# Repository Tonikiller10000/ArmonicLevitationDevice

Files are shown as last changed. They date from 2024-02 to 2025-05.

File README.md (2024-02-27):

# ArmonicLevitationDevice

## Description:
<table>
  <tr>
    <td> 
      This levitation device uses an NE555 with an TC78H621FNG Dual-Bridge driver to generate a 40KHz sine wave signal witch is sent back at the rigth distance to make zones of high and low pressure in witch it can trap small objects.
    </td>
    <td>
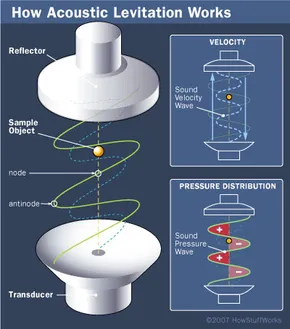
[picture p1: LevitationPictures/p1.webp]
       </td>
  </tr>
</table>

<table>
  <tr>
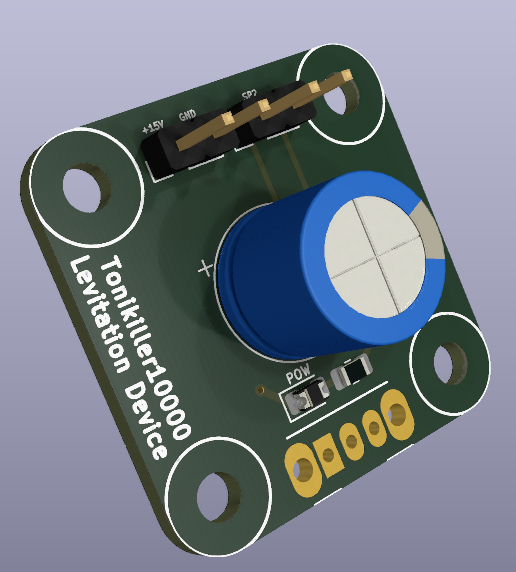
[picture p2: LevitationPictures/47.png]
    <td></td>
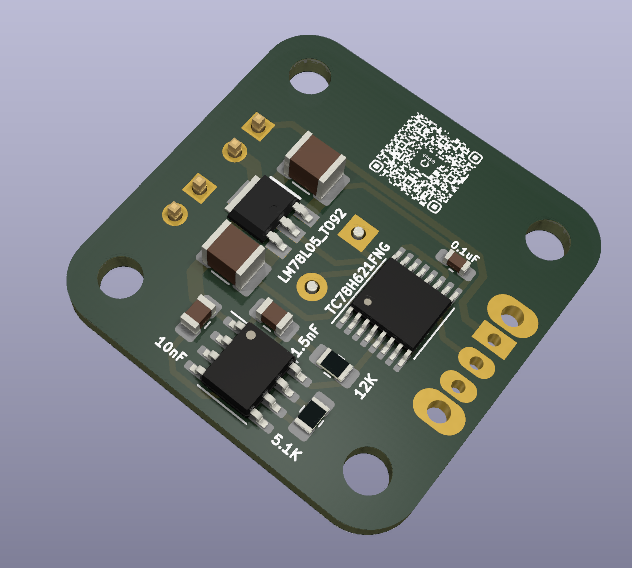
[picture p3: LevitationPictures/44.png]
    <td></td>
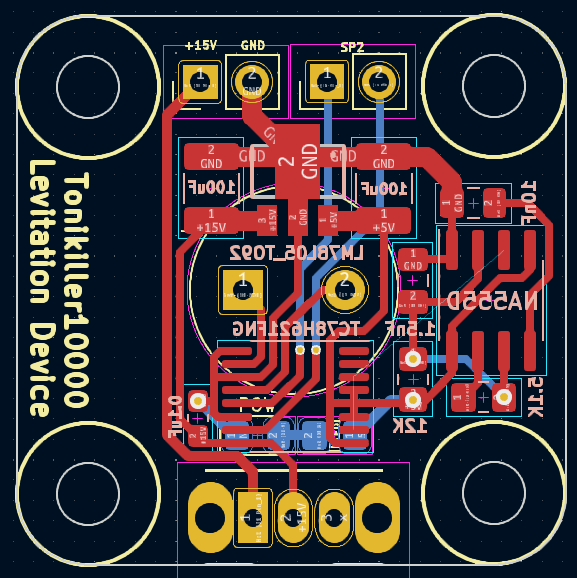
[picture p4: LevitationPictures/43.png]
    <td></td>
  </tr>
</table>

## Schematic:
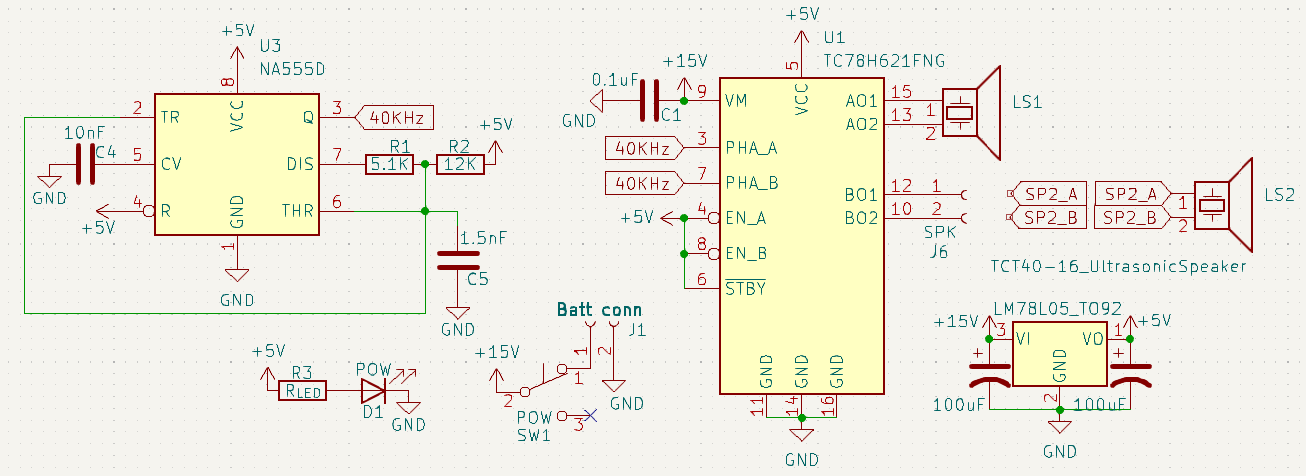
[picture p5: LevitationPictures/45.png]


## How/where to use:
It can be powered with a 9V battery. (5-15v operating voltage range) 
Because of it`s design, multiple tipes of transmiters/transducers can be used by bending the pins. 
To use it, you can use only one board/transmitter ans a close flat surface to reflect the wave. 
For a stronger hold, you can use another transmitter connected to the SP2 pins.

> [!IMPORTANT]
> Change the distance between the transmitter1 and the surface/transmitter2 to create the nodes and antinodes for the project to work.

<table>
  <tr>
    <td> 
    This king of technology, can be used in medical industry to observe and experiment with liquids without making contact with them.</td>
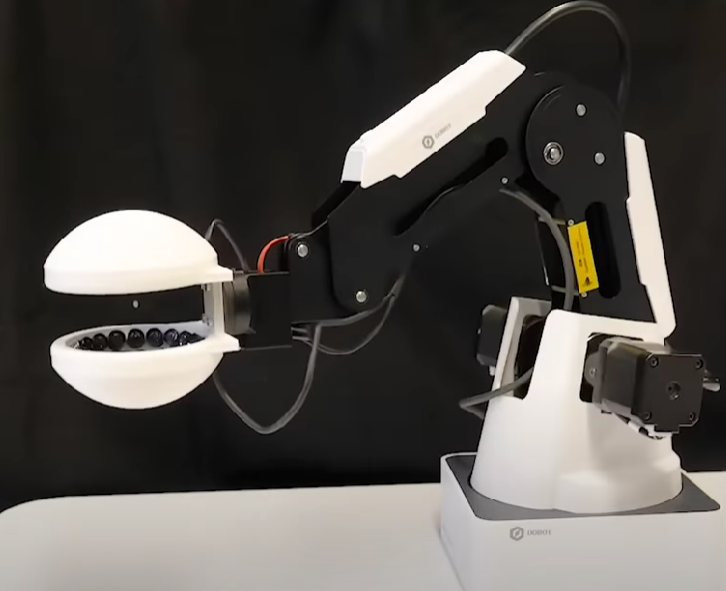
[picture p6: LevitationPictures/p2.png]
    <td></td>
  </tr>
</table>

## Links:
- TC78H621FNG datasheet (Dual-Bridge driver): https://toshiba.semicon-storage.com/info/TC78H621FNG_datasheet_en_20170410.pdf?did=57992&prodName=TC78H621FNG
- 78L05 datasheet (voltage regulator): https://www.sparkfun.com/datasheets/Components/LM7805.pdf
- NE555 datasheet (timer): https://pdf1.alldatasheet.com/datasheet-pdf/view/17972/PHILIPS/NE555.html
- Ultrasonic transducer: https://www.murata.com/-/media/webrenewal/products/sensor/ultrasonic/open/datasheet_maopn.ashx
- general transducers: https://tecsho.com/Download/Download/126816/fp

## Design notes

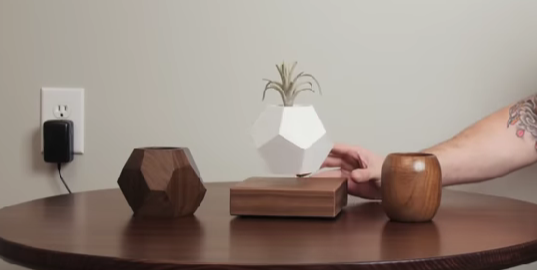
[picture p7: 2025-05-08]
LevitationPictures/Screenshot 2024-01-10 024258.png

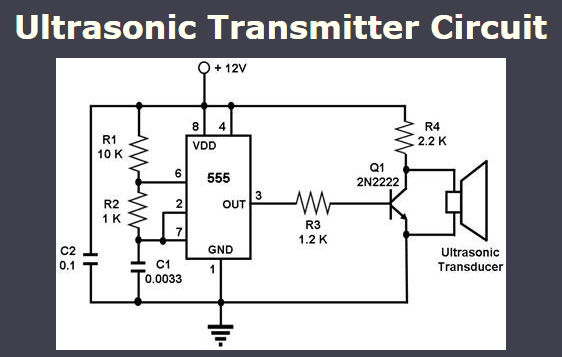
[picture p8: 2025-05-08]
LevitationPictures/{7252BA24-0894-4667-9A59-82356E71AA2C}.png

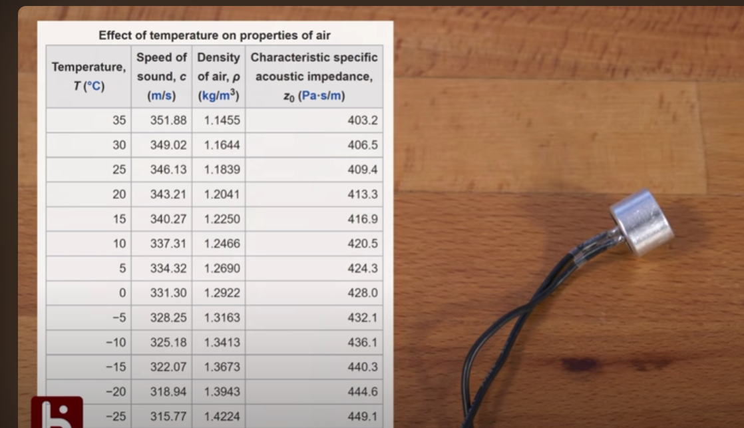
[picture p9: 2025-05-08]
LevitationPictures/Screenshot 2023-12-14 022056.png

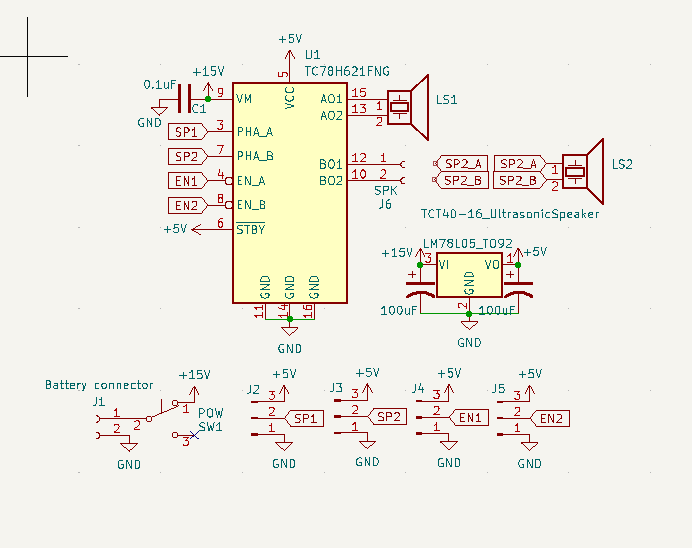
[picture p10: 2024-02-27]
LevitationPictures/sch.png

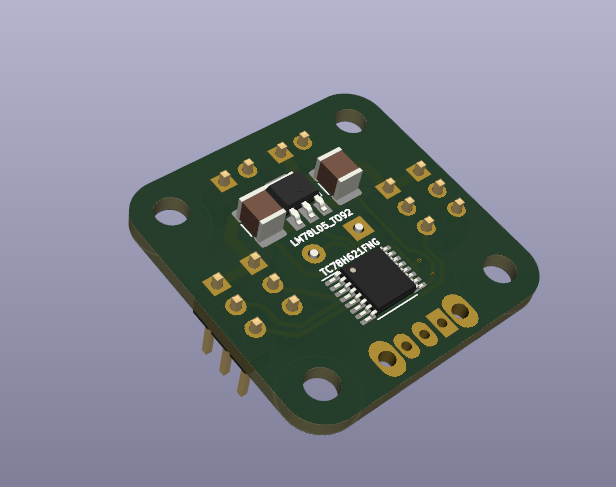
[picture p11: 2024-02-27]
LevitationPictures/down.png

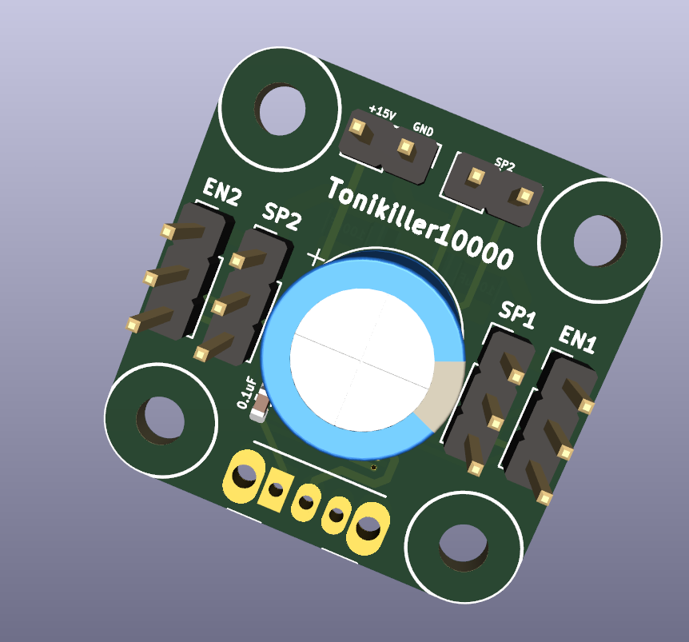
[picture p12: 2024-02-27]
LevitationPictures/up.png

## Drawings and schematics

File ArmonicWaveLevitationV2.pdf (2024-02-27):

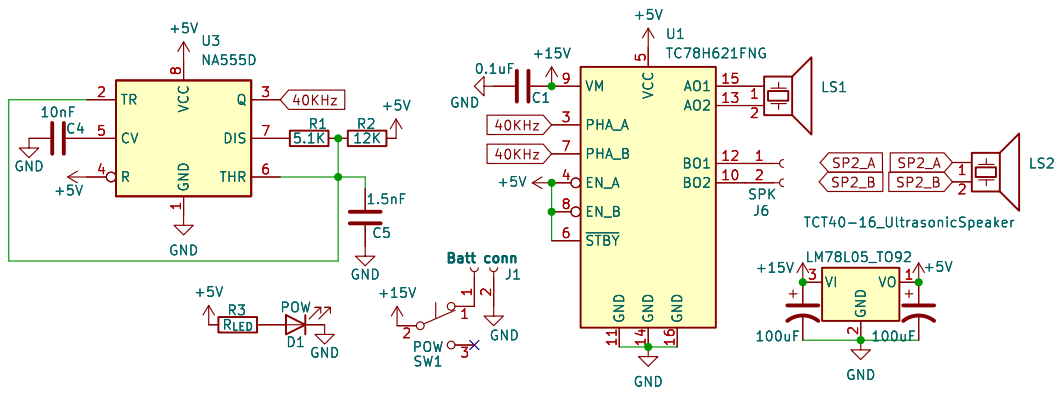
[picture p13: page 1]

Id: 1/1 Title: File: ArmonicWaveLevitation.kicad_sch Sheet: / GND

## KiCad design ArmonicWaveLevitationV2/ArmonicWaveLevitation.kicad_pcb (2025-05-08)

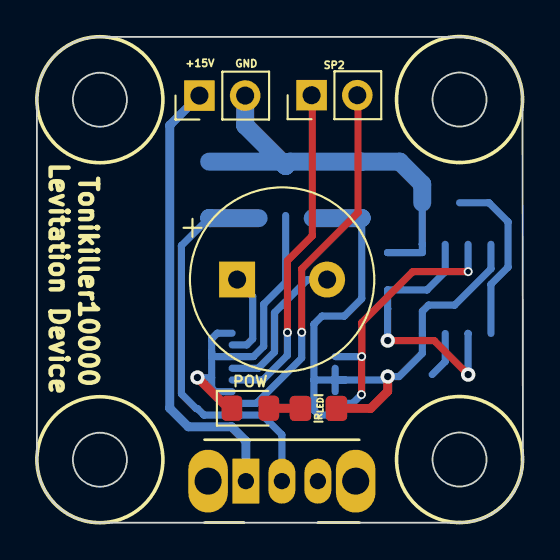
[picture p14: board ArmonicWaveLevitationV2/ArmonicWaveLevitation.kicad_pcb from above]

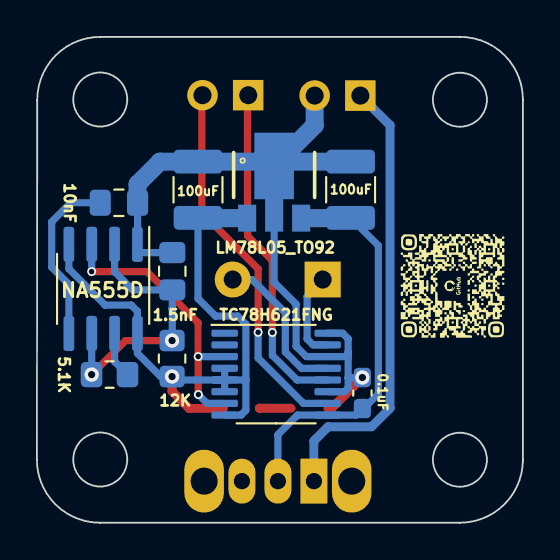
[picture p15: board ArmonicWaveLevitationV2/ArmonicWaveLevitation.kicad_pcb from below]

Board: 2 copper layers, 27.0 x 27.0 mm, 16 parts (10 on the bottom side), 13 nets.

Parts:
C1: 0.1uF; C_0603_1608Metric_Pad1.08x0.95mm_HandSolder
C2, C3: 100uF; C_1210_3225Metric_Pad1.33x2.70mm_HandSolder
C4: 10nF; C_0805_2012Metric_Pad1.18x1.45mm_HandSolder
C5: 1.5nF; C_0805_2012Metric_Pad1.18x1.45mm_HandSolder
D1: POW; D_0805_2012Metric_Pad1.15x1.40mm_HandSolder
J1: Batt conn; PinHeader_1x02_P2.54mm_Vertical
J6: SPK; PinHeader_1x02_P2.54mm_Vertical
LS1: TCT40-16_UltrasonicSpeaker; CP_Radial_D10.0mm_P5.00mm
R1: 5.1K; R_0805_2012Metric_Pad1.20x1.40mm_HandSolder
R2: 12K; R_0805_2012Metric_Pad1.20x1.40mm_HandSolder
R3: R_{LED}; R_0805_2012Metric_Pad1.20x1.40mm_HandSolder
SW1: POW; SW_CuK_OS102011MA1QN1_SPDT_Angled
U1: TC78H621FNG; TSSOP-16_4.4x5mm_P0.65mm
U2: LM78L05_TO92; PK(R-PSSO-F3)
U3: NA555D; SOIC-8_3.9x4.9mm_P1.27mm

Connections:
40KHz: U1.3 (PHA_A), U1.7 (PHA_B), U3.3 (Q)
+5V: C3.1, R2.2, R3.1, U1.4 (EN_A), U1.5 (VCC), U1.6 (~STBY), U1.8 (EN_B), U2.1 (VO), U3.4 (R), U3.8 (VCC)
+15V: C1.2, C2.1, SW1.2 (B), U1.9 (VM), U2.3 (VI)
GND: C1.1, C2.2, C3.2, C4.1, C5.1, D1.1 (K), J1.2, U1.11 (GND), U1.14 (GND), U1.16 (GND), U2.2 (GND), U3.1 (GND)
unnamed: D1.2 (A), R3.2
unnamed: J1.1, SW1.1 (A)
unnamed: J6.1, U1.12 (BO1)
unnamed: J6.2, U1.10 (BO2)
unnamed: LS1.1, U1.15 (AO1)
unnamed: LS1.2, U1.13 (AO2)
unnamed: C4.2, U3.5 (CV)
unnamed: R1.1, U3.7 (DIS)
unnamed: C5.2, R1.2, R2.1, U3.2 (TR), U3.6 (THR)

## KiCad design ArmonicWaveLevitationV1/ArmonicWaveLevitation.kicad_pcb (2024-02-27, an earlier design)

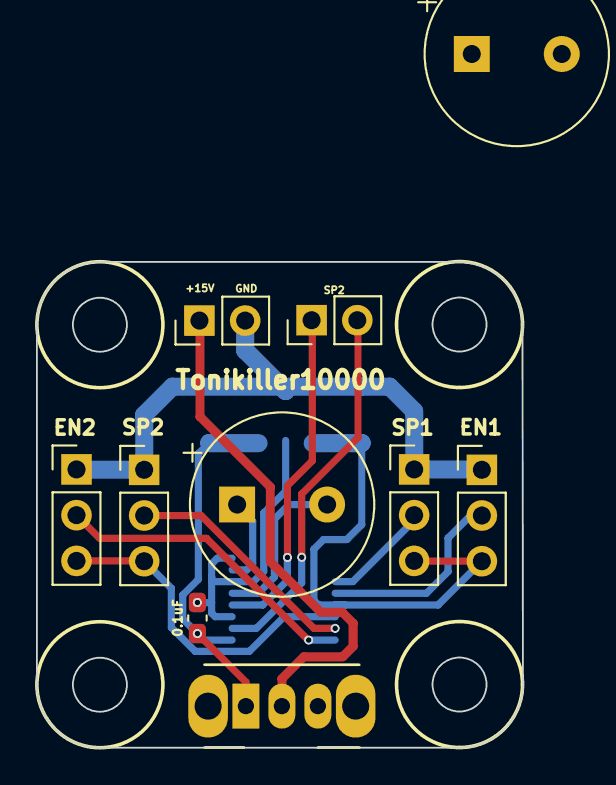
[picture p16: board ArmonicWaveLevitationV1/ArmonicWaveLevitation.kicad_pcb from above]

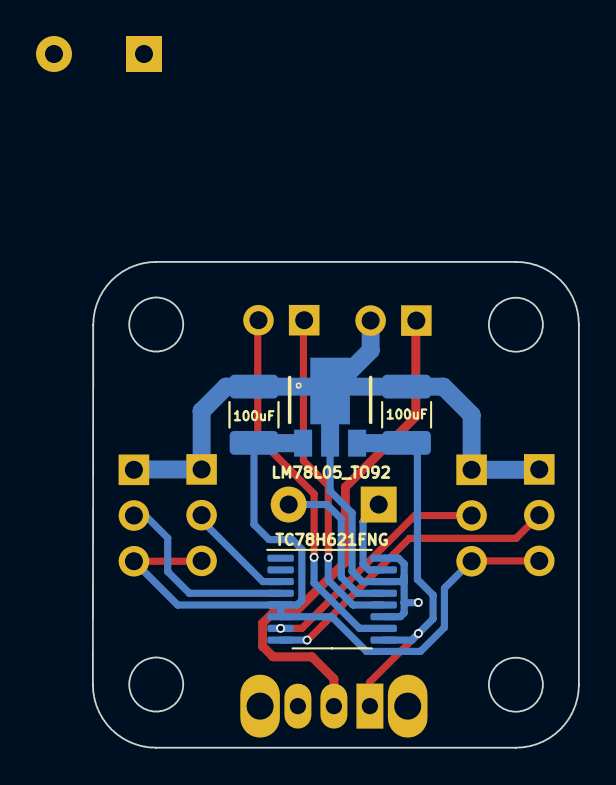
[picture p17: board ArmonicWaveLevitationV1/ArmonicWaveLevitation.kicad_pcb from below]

Board: 2 copper layers, 27.0 x 27.0 mm, 14 parts (4 on the bottom side), 12 nets.

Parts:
C1: 0.1uF; C_0603_1608Metric_Pad1.08x0.95mm_HandSolder
C2, C3: 100uF; C_1210_3225Metric_Pad1.33x2.70mm_HandSolder
J1: Battery connector; PinHeader_1x02_P2.54mm_Vertical
J2: SP1; PinHeader_1x03_P2.54mm_Vertical
J3: SP2; PinHeader_1x03_P2.54mm_Vertical
J4: EN1; PinHeader_1x03_P2.54mm_Vertical
J5: EN2; PinHeader_1x03_P2.54mm_Vertical
J6: SPK; PinHeader_1x02_P2.54mm_Vertical
LS1, LS2: TCT40-16_UltrasonicSpeaker; CP_Radial_D10.0mm_P5.00mm
SW1: POW; SW_CuK_OS102011MA1QN1_SPDT_Angled
U1: TC78H621FNG; TSSOP-16_4.4x5mm_P0.65mm
U2: LM78L05_TO92; PK(R-PSSO-F3)

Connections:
+5V: C3.1, J2.3, J3.3, J4.3, J5.3, U1.5 (VCC), U1.6 (~STBY), U2.1 (VO)
+15V: C1.2, C2.1, SW1.1 (A), U1.9 (VM), U2.3 (VI)
EN1: J4.2, U1.4 (EN_A)
EN2: J5.2, U1.8 (EN_B)
GND: C1.1, C2.2, C3.2, J1.2, J2.1, J3.1, J4.1, J5.1, U1.11 (GND), U1.14 (GND), U1.16 (GND), U2.2 (GND)
unnamed: J1.1, SW1.2 (B)
unnamed: J6.1, U1.12 (BO1)
unnamed: J6.2, U1.10 (BO2)
unnamed: LS1.1, U1.15 (AO1)
unnamed: LS1.2, U1.13 (AO2)
SP1: J2.2, U1.3 (PHA_A)
SP2: J3.2, U1.7 (PHA_B)
